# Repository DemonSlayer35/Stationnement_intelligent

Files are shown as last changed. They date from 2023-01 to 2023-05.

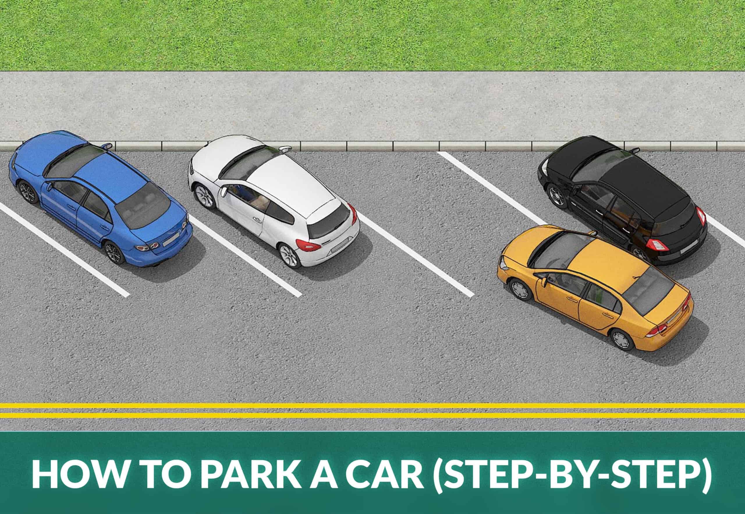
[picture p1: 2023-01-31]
data_parking/1images/HOW-TO-PARK-A-CAR-STEP-BY-STEP-scaled.jpg

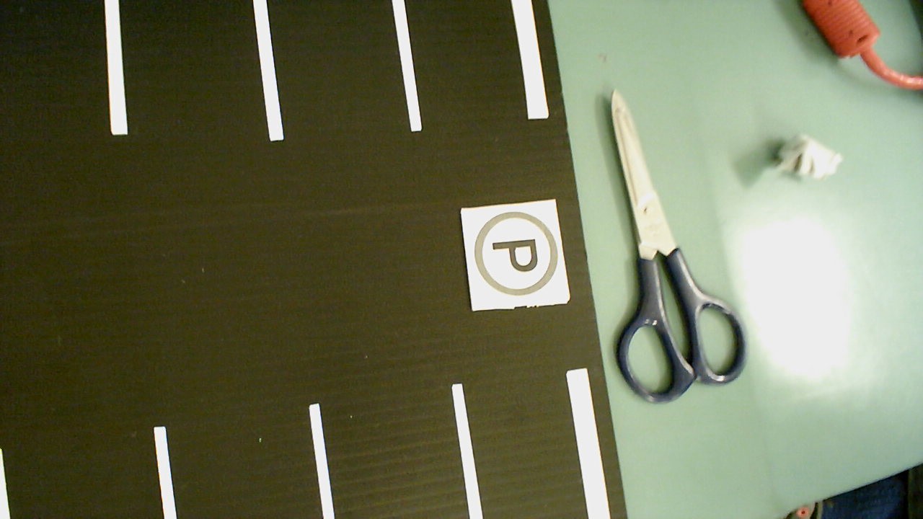
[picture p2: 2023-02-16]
data_parking/images/WIN_20230214_13_57_14_Pro.jpg

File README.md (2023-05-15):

# Stationnement intelligent
Projet de fin de DEC en TSO (Etienne Dubé et Mohammad Barin Wahidi)

## Pour démarrer le projet, il faut d'abord suivre les étapes d'installation des fichiers Installation.md 
(Stationnement_intelligent/Installation.md et Stationnement_intelligent/code_esp/Installation.md)
https://github.com/DemonSlayer35/Stationnement_intelligent/blob/main/Installation.md et
https://github.com/DemonSlayer35/Stationnement_intelligent/blob/main/code_esp/Installation.md

## Ensuite, il faut suivre les étapes d'opération des fichiers Procedure.md
(Stationnement_intelligent/page_web/Procedure.md et Stationnement_intelligent/code_esp/Procedure.md)
https://github.com/DemonSlayer35/Stationnement_intelligent/blob/main/page_web/Procedure.md et https://github.com/DemonSlayer35/Stationnement_intelligent/blob/main/code_esp/Procedure.md

## Installation.md 
* Ce fichier contient les procédures d'installation de la suite Yolov5 et les étapes pour l'entraînement de l'IA ainsi que la détection d'objets.

## KiCad
* Ce dossier contient le projet KiCad (schéma électrique, PCB et fichiers de fabrication) de l'ESP32 pour la barrière de stationnement.

## code 
* Ce dossier contient les scripts en Python pour la détection des images avec la caméra et l'affichage du stationnement sur un écran.
* Le code envoie les résultats de la détection d'emplacements libres par MQTT au broker pour la construction de la page Web du stationnement.

## code_esp
* Ce dossier contient le code (code_esp.ino) à téléverser dans l'ESP, ainsi que les fichiers (dans le dossier /data) à téléverser dans le système de fichiers de l'ESP32. 
* Le code de l'ESP génère un point d'accès qui sert la page Web du stationnement intelligent via un portail captif.

## data_parking 
* Ce dossier contient les images de stationnement pour l'entraînement de l'IA et les étiquettes correspondantes (vide, plein, logo).
* Sont aussi inclus les modèles résultants de l'entraînement qui permettent de détecter les étiquettes voulues.

## page_web
* Ce dossier contient les fichiers de code pour la génération de la page Web affichant les places de stationnement.

## stl
* Ce dossier contient les fichiers 3D de la barrière.

## schema.drawio
* Ce fichier est un schéma bloc du fonctionnement du projet de stationnement intelligent (à ouvrir avec draw.io)

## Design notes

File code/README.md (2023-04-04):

# camera.py 
Contient une version améliorée de Projet.py (ajout de la moyenne des résultats, numérotation des parkings et simplification du code).

# ClassCamera.py
Tentative d'Etienne d'améliorer camera.py pour gérer plusieurs caméras à la fois.

# Projet.py 
Contient un code en Python qui permet de détecter les voitures dans le stationnement en traçant des rectangles autour des emplacements.

# ecran.py
Contient un code en Python pour l'affichage graphique du stationnement.

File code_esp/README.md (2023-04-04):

## Installation.md 
* Ce fichier contient les procédures d'installation du board ESP32 et des librairies pour le code dans l'IDE Arduino.

## Procedure.md
* Procédure pour faire rouler l'ESP en mode point d'accès avec un portail captif affichant le schéma du stationnement

## code_esp.ino
* Code à téléverser dans l'ESP32 pour générer un point d'accès qui sert la page Web du stationnement intelligent via un portail captif.
* L'ESP est mis en mode point d'accès et en mode station.
* Le côté station se connecte au réseau spécifié. Cette connexion servira à la récupération des données MQTT depuis le broker.
Il faut donc que le broker soit connecté au même réseau.
* Le côté point d'accès permet aux usagers de se connecter à l'ESP.
* Via un serveur DNS, les usagers connectés au point d'accès sont redirigés vers le portail captif.
* Lorsqu'un message (la liste de places libres) est reçu par MQTT, le point de terminaison (endpoint) HTTP à l'adresse "/content" est mis à jour avec
le contenu de la nouvelle liste.
* Ainsi, lorsque le code javascript effectue (aux 2 secondes) une requête GET vers "/content", il reçoit une réponse contenant le contenu de la liste sous forme de JSON.

## data
* Dossier contenant les fichiers pour la page Web à téléverser dans le système de fichiers de l'ESP.

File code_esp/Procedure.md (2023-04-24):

# Procédure pour faire rouler l'ESP en mode point d'accès avec un portail captif affichant le schéma du stationnement

1. Récupérer le dossier code_esp.
2. Ouvrir le fichier code_esp.ino dans l'IDE Arduino.
3. Connecter l'ESP à l'ordinateur. Sélectionner le type de carte (ex. : ESP32-WROOM-DA Module) et le port correspondant.
Assurez-vous aussi de rentrer les identifiants Wi-Fi correspondants ainsi que l'adresse du broker MQTT.



4. Téléverser le code à l'intérieur de l'ESP. 
(Si la connexion ne fonctionne pas, il faut appuyer sur le bouton BOOT pendant une seconde environ lorsque la console affiche Connecting...)
5. Aller dans Outils > ESP32 Data Sketch Upload et attendre que les fichiers soient téléchargés dans la mémoire.



6. Un point d'accès nommé Parking devrait apparaître dans la liste des réseaux disponibles. En vous y connectant, le schéma
du stationnement devrait apparaître après quelques secondes.

(Vous pouvez vérifier dans le moniteur série de l'IDE Arduino si tout est fonctionnel.)

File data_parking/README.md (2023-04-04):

## bestv5m.pt
* Le dernier modèle de détection entraîné pour détecter les logos de parking ainsi que les emplacements libres et occupés.

## hyps
* Contient les paramètres d'entraînement supplémentaires (translation, rotation, homothétie, etc.)

## images
* Contient les images utilisées pour l'entraînement de l'intelligence artificielle.

## labels
* Contient les étiquettes (vide, plein, logo) associées aux images de l'entraînement.

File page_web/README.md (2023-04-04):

## Procedure.md
* Procédure pour faire rouler la page Web contenant le schéma du stationnement accessible à tous

## page_web.html
* Ce fichier HTML contient une page web qui affiche un canevas avec une texture d'asphalte. 

* Le canevas s'ajuste selon la taille de l'affichage. 

* Le script JavaScript situé dans le fichier "C:/nginx-1.23.3/js/script.js" est chargé sur la page web.

* C'est le script qui se charge de dessiner les emplacements de stationnement.

## script.js
* Ce fichier JavaScript est utilisé pour dessiner une grille de parkings sur un canevas HTML et
pour récupérer une liste de disponibilité de ces parkings à partir d'un serveur MQTT (Mosquitto).

* Il commence par définir les dimensions de l'écran de dessin et la variable "obj" qui sera utilisée pour stocker les données récupérées depuis le topic MQTT.

* Ensuite, il va récupérer les données du topic MQTT en utilisant l'URL du serveur MQTT (IP de l'hôte:8080).

* Les parkings disponibles sont remplis de vert et les parkings occupés sont remplis de rouge. Les numéros de parking sont également affichés à l'intérieur des rectangles.

* Toutes les 2 secondes, les données affichées sur le canevas HTML sont mises à jour.

## test_web.py
* Ce fichier est un script Python pour tester la publication de la liste en MQTT au lieu de Flask.

* Dans le code, il y a une boucle qui change l'état des stationnements aux secondes.

## app.py (Remplacé par MQTT)
~~* Le fichier app.py est un programme Python qui utilise le framework Flask pour créer une API web. 
L'API permet au fichier camera.py de mettre à jour la liste moyenne de l'état des 18 stationnements.~~

~~* Lorsqu'un utilisateur envoie une requête GET à la route "/moyenne", l'API renvoie la liste moyenne sous forme de JSON.~~

~~* Lorsque camera.py envoie une requête POST à la route "/moyenne" avec une liste de 18 valeurs, 
l'API met à jour la liste moyenne avec les nouvelles valeurs et renvoie la liste mise à jour sous forme de JSON.~~

~~* Le module flask_cors est également utilisé pour permettre l'accès à l'API depuis n'importe quel site web,
en contournant les restrictions de sécurité normalement en place pour les requêtes effectuées à partir de sites tiers.~~

~~* Il faut installer flask avec ```pip install flask``` et flask_cors avec ```pip install -U flask-cors```.~~

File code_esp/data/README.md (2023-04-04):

## captive_portal.html
* Ce fichier HTML contient une page web qui affiche un canevas avec un fond gris. 

* Le canevas s'ajuste selon la taille de l'affichage. 

* Le script JavaScript situé dans le même dossier est chargé sur la page web.

* C'est le script qui se charge de dessiner les emplacements de stationnement.

## script.js
* Ce fichier JavaScript est utilisé pour dessiner une grille de parkings sur un canevas HTML et
pour récupérer une liste de disponibilité de ces parkings à partir d'un serveur MQTT (Mosquitto).

* Il commence par définir les dimensions de l'écran de dessin et la variable "obj" qui sera utilisée pour stocker les données de la liste de places JSON.

* Les parkings disponibles sont remplis de vert et les parkings occupés sont remplis de rouge. Les numéros de parking sont également affichés à l'intérieur des rectangles.

* Toutes les 2 secondes, il va récupérer les données depuis l'endpoint /content pour mettre à jour les données affichées sur le canevas HTML.

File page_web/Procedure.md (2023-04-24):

# Procédure pour faire rouler la page Web contenant le schéma du stationnement accessible à tous

1. Installer paho-mqtt (client MQTT) avec ```pip install paho-mqtt``` dans une console cmd.
Télécharger NGINX à partir du site officiel : https://nginx.org/en/download.html, puis décompresser le dossier.

2. Récupérer les fichiers page_web.html (dans page_web), script.js (dans page_web), camera.py (dans code) et le modèle bestv5m.pt (dans data_parking).

3. Créer un dossier js (pour les fichiers JavaScript) dans le répertoire de NGINX et y déposer script.js :



4. Placer le fichier page_web.html dans le dossier html de NGINX.

5. Ouvrir le fichier nginx.conf (configuration de NGINX) situé dans le dossier conf de NGINX :



6. Dans la section non-commentée commençant par server{listen 80;, ajouter un bloc pour l'emplacement du dossier JavaScript comme suit :



(Mettre le chemin correspondant en conséquence.)

7. Enregistrer le fichier et fermer nginx.conf (Notez qu'il faut repartir nginx.exe à chaque modification.)

8. Modifier le fichier script.js en entrant l'adresse IP de l'hôte pour la connexion MQTT et le bon nom de topic:
```
// Créez un nouveau client MQTT
const client = new Paho.Client("10.240.9.128", 8080, "myclientid_");
const topic = "parking/A";
```

9. Enregistrer le fichier et repartir nginx.exe

10. Assurez-vous que le chemin du modèle utilisé est correct dans le fichier camera.py 
  - ``` model = torch.hub.load('C:/yolov5', 'custom', path='C:/yolov5/Stationnement_intelligent/data_parking/bestv5m.pt', source='local') ```

11. Assurez-vous que la bonne caméra est utilisée dans le fichier camera.py 
  - ```cap = cv2.VideoCapture(0)  # 0 = Webcam intégrée ; 1 = Caméra USB```

12. Démarrer NGINX en double-cliquant sur nginx.exe (C'est normal si rien ne s'affiche.)
  - Si vous voulez être sûr que NGINX fonctionne, aller à l'adresse localhost et vous devriez voir la page index.html suivante :



13. Télécharger Mosquitto à partir du site officiel : https://mosquitto.org/download/.

14. Ouvrir le fichier de configuration de Mosquitto (C:\Program Files\mosquitto\mosquitto.conf) 
et ajouter les lignes suivantes à la fin du fichier:
```
listener 1883
listener 8080 
protocol websockets
allow_anonymous true
socket_domain ipv4
```


15. Démarrer le serveur Mosquitto avec la commande ```mosquitto -c mosquitto.conf``` dans une console cmd.
(Si la console affiche que le serveur est déjà occupé, vous pouvez tuer le service Mosquitto à partir des Services Windows ou avec
la commande ```taskkill /im mosquitto.exe /f``` dans une console cmd exécutée en tant qu'administrateur.

16. Exécuter le fichier 📷camera.py depuis une console cmd avec ```py camera.py```.
  - Cela va démarrer la détection des emplacements de stationnement. Après chaque cycle de 20 frames, la liste est mise à jour sur le serveur Mosquitto
  à [l'adresse IP de l'hôte]:1883
  (La page va se mettre à jour avec les données MQTT envoyées au port 8080).

17. Accéder au 🕸️site Web à [l'adresse IP de l'hôte]/page_web.html
(Les autres usagers peuvent aussi accéder à la page.)



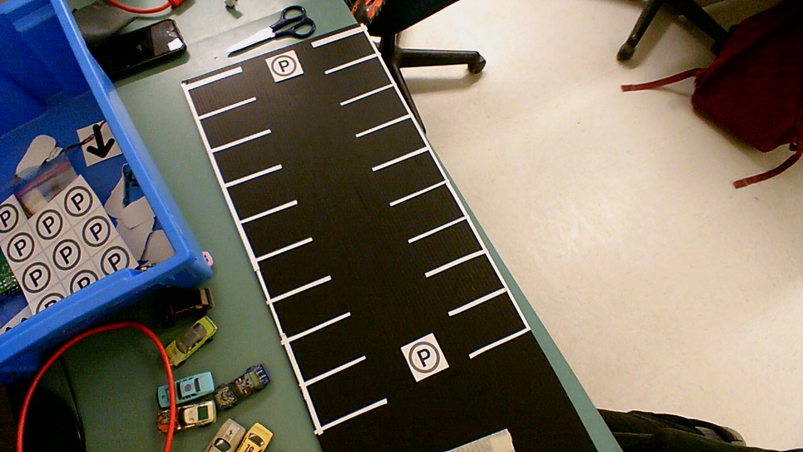
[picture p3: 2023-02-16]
data_parking/images/WIN_20230214_13_57_02_Pro.jpg

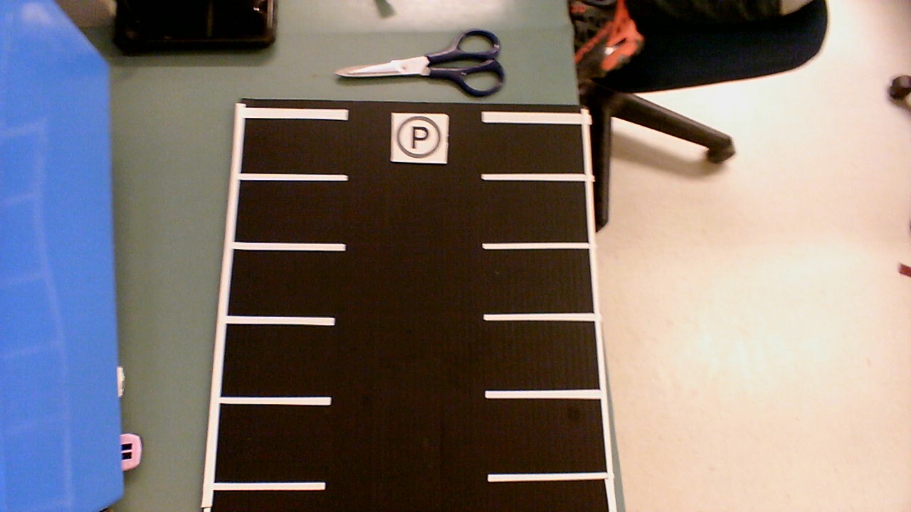
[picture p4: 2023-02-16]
data_parking/images/WIN_20230214_13_57_19_Pro.jpg

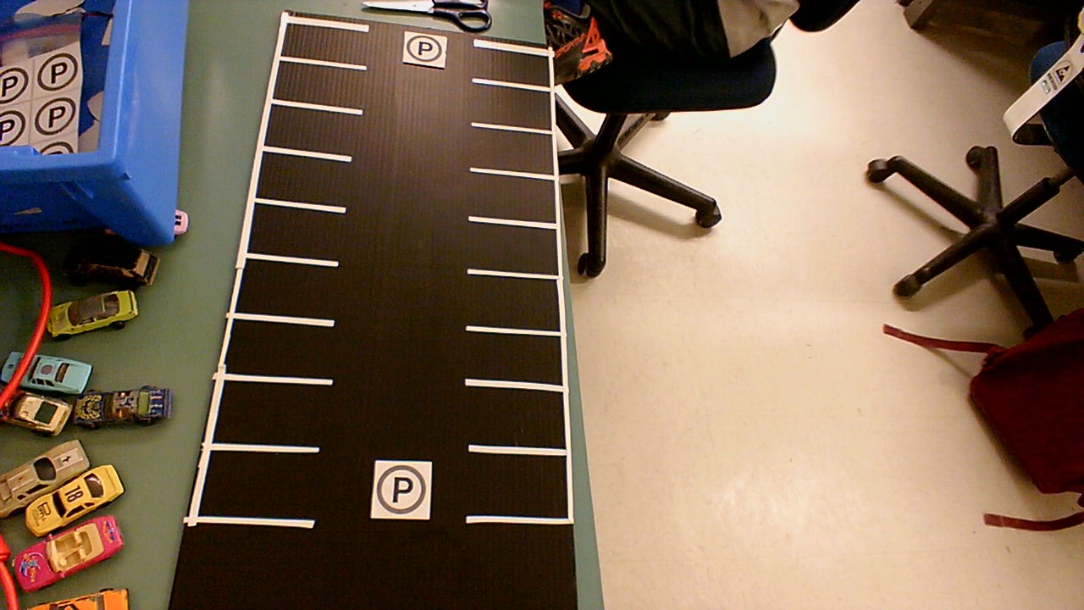
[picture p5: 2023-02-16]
data_parking/images/WIN_20230214_13_56_37_Pro.jpg

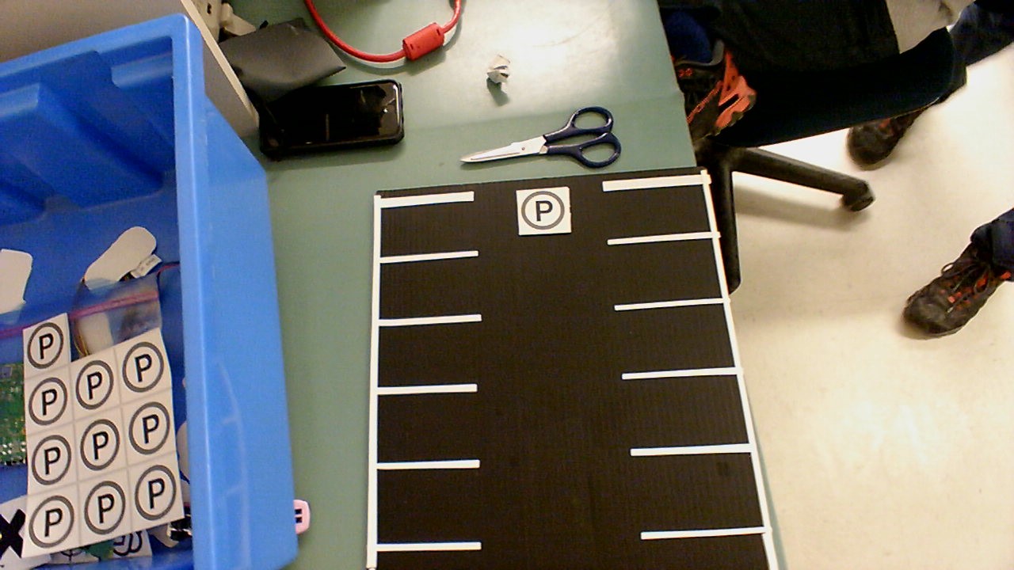
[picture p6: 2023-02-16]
data_parking/images/WIN_20230214_13_57_23_Pro.jpg

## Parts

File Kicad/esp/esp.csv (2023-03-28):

# | Reference | Qty | Value | Footprint | DNP
1 | C1, C2, C3, C4, C5, C6, C7 | 7 | 0.1µ | Capacitor_SMD:C_0805_2012Metric_Pad1.18x1.45mm_HandSolder
2 | D1 | 1 | LED_TX_Bleu | LED_SMD:LED_0805_2012Metric_Pad1.15x1.40mm_HandSolder
3 | D2 | 1 | LED_RX_Rouge | LED_SMD:LED_0805_2012Metric_Pad1.15x1.40mm_HandSolder
4 | D3 | 1 | D_Schottky | Diode_SMD:D_0805_2012Metric_Pad1.15x1.40mm_HandSolder
5 | J1, J2 | 2 | ~ | TerminalBlock:TerminalBlock_bornier-2_P5.08mm
6 | J3 | 1 | LED_R | Connector_PinHeader_2.54mm:PinHeader_1x02_P2.54mm_Vertical
7 | J4 | 1 | SW_Open | Connector_PinHeader_2.54mm:PinHeader_1x02_P2.54mm_Vertical
8 | J5 | 1 | Sensor_car_in | Connector_PinHeader_2.54mm:PinHeader_1x03_P2.54mm_Vertical
9 | J6 | 1 | Sensor_gate_open | Connector_PinHeader_2.54mm:PinHeader_1x03_P2.54mm_Vertical
10 | J7 | 1 | LED_V | Connector_PinHeader_2.54mm:PinHeader_1x02_P2.54mm_Vertical
11 | J8 | 1 | SW_Close | Connector_PinHeader_2.54mm:PinHeader_1x02_P2.54mm_Vertical
12 | J9 | 1 | Sensor_car_out | Connector_PinHeader_2.54mm:PinHeader_1x03_P2.54mm_Vertical
13 | J10 | 1 | Sensor_gate_close | Connector_PinHeader_2.54mm:PinHeader_1x03_P2.54mm_Vertical
14 | J11, J12 | 2 | Conn_01x19_Pin | Connector_PinHeader_2.54mm:PinHeader_1x19_P2.54mm_Vertical
15 | K1, K2 | 2 | FINDER-30.22 | Relay_THT:Relay_DPDT_Finder_30.22
16 | P1 | 1 | USB_C_Plug_USB2.0 | Connector_USB:USB_C_Receptacle_GCT_USB4105-xx-A_16P_TopMnt_Horizontal
17 | Q1, Q2 | 2 | NPN | Package_TO_SOT_SMD:SOT-23
18 | R1, R2, R9, R10, R16, R21 | 6 | 10K | Resistor_SMD:R_0805_2012Metric_Pad1.20x1.40mm_HandSolder
19 | R3, R4, R11, R12, R13, R15, R17 | 7 | R | Resistor_SMD:R_0805_2012Metric_Pad1.20x1.40mm_HandSolder
20 | R5, R6 | 2 | 150 | Resistor_SMD:R_0805_2012Metric_Pad1.20x1.40mm_HandSolder
21 | R7, R8 | 2 | 330 | Resistor_SMD:R_0805_2012Metric_Pad1.20x1.40mm_HandSolder
22 | R14, R20 | 2 | 300 | Resistor_SMD:R_0805_2012Metric_Pad1.20x1.40mm_HandSolder
23 | R18, R19 | 2 | 470 | Resistor_SMD:R_0805_2012Metric_Pad1.20x1.40mm_HandSolder
24 | SW1, SW2 | 2 | SW_Push | Button_Switch_SMD:SW_SPST_CK_RS282G05A3
25 | U1 | 1 | AMS1117-3.3 | Package_TO_SOT_SMD:SOT-223-3_TabPin2
26 | U2 | 1 | FT232RL | Package_SO:SSOP-28_5.3x10.2mm_P0.65mm
27 | U3 | 1 | ULN2003 | Package_SO:SO-16_3.9x9.9mm_P1.27mm
28 | U4 | 1 | ESP32-WROOM-E | Espressif:ESP32-WROOM-32E

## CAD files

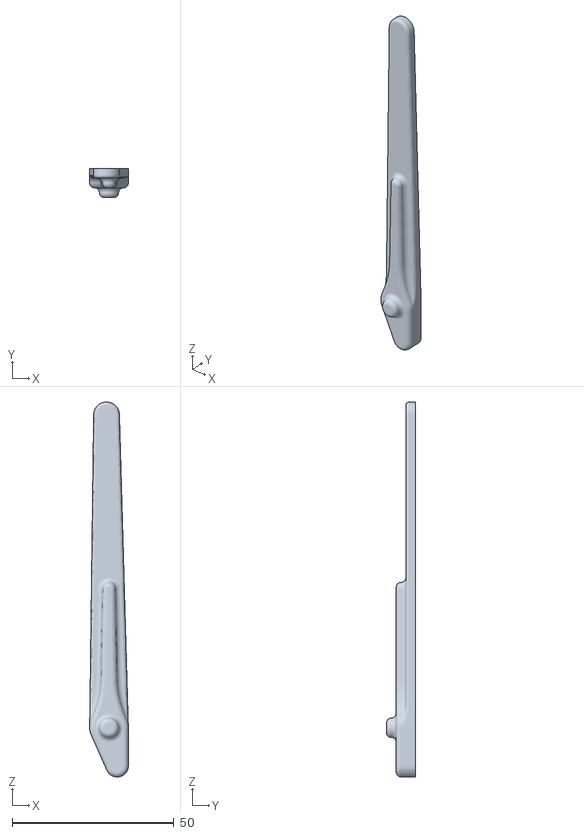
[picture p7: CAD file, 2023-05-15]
stl/lever_gate.stl
12.0 x 9.00 x 116.0

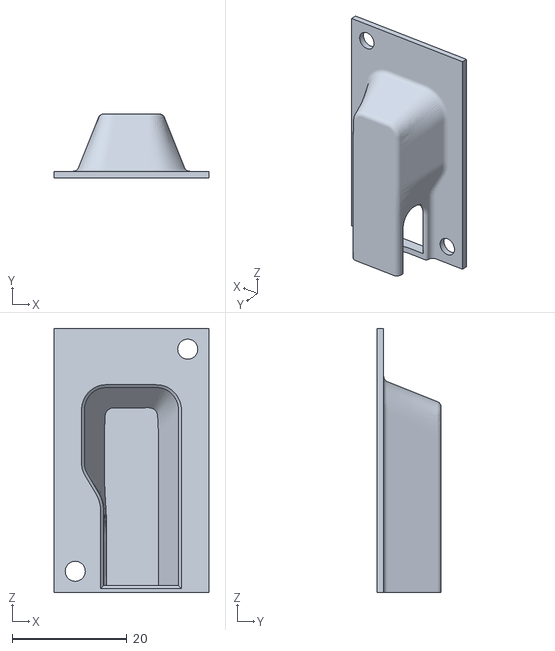
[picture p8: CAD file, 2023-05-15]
stl/cover_gate.stl
27.0 x 11.2 x 46.0

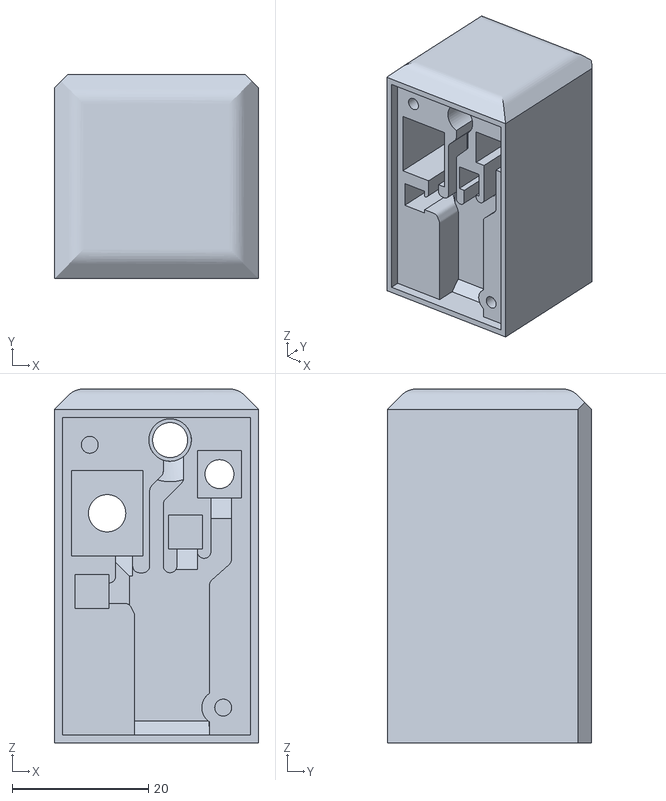
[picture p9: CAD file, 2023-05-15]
stl/stand_gate.stl
30.0 x 30.0 x 52.0

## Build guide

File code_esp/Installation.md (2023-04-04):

## Installer le board ESP32 dans l’IDE Arduino. (https://randomnerdtutorials.com/installing-the-esp32-board-in-arduino-ide-windows-instructions/)
1.	Dans l'IDE Arduino (pas 2.0), aller dans Fichier> Préférences



2.	Entrer l'adresse suivante dans le champ “URL de gestionnaire de cartes supplémentaires” :
https://raw.githubusercontent.com/espressif/arduino-esp32/gh-pages/package_esp32_index.json
Puis, cliquer sur le bouton “OK”:

 
 
3.	Ouvrir le Gestionnaire de carte. Aller dans Outils > Type de carte > Gestionnaire de carte

 

4.	Chercher ESP32 et appuyer sur le bouton Installer de “esp32 by Espressif Systems“:

 

## Installer ESP32 Filesystem Uploader dans l’IDE Arduino (https://randomnerdtutorials.com/install-esp32-filesystem-uploader-arduino-ide/)

1) Aller à l'adresse suivante https://github.com/me-no-dev/arduino-esp32fs-plugin/releases/ et télécharger le dossier compressé ESP32FS-1.0.zip

 
 
2) Trouver le dossier des croquis. Dans l'IDE Arduino, aller dans Fichier > Préférences et afficher le dossier des croquis.
Par exemple, le chemin peut ressembler à cela: C:\Users\user\Documents\Arduino.

 
 
3) Aller dans le dossier des croquis et créer un dossier tools.

 
 
4) Décompresser le dossier .zip. Ouvrez-le et copiez le dossier ESP32FS dans le dossier tools précédemment créé.
La structure de fichier devrait ressembler à: <Dossier-des-croquis>/tools/ESP32FS/tool/esp32fs.jar
  
 
 
5) Finalement, redémarrer (rouvrir) l'IDE Arduino. Pour vérifier si le plugin a été installé correctement, ouvrir l'IDE Arduino.
Sélectionner votre board ESP32, aller dans Outils et vérifier que vous avez l'option “ESP32 Sketch Data Upload“.
  
 

Pour le MQTT, il faut installer la libraire PubSubClient via Outils > Gérer les bibliothèques

 
  
## Installer la librairie ESPAsyncWebServer
 
1) Cliquer sur ce lien https://github.com/me-no-dev/ESPAsyncWebServer/archive/master.zip pour télécharger la librairie.
 
2) Décompresser le dossier .zip. Vous devriez obtenir un dossier ESPAsyncWebServer-master.
 
3) Renommer le dossier ESPAsyncWebServer-master en ESPAsyncWebServer.
 
4) Déplacer le dossier ESPAsyncWebServer vers votre dossier de libraires pour l'IDE Arduino.
Par exemple, le chemin peut ressembler à cela: C:\Users\user\Documents\Arduino\libraries.
 

 
## Installer la librairie Async TCP
 
1) Cliquer sur ce lien https://github.com/me-no-dev/AsyncTCP/archive/master.zip pour télécharger la librairie.
 
2) Décompresser le dossier .zip. Vous devriez obtenir un dossier AsyncTCP-master.
 
3) Renommer le dossier AsyncTCP-master en AsyncTCP.
 
4) Déplacer le dossier AsyncTCP vers votre dossier de libraires pour l'IDE Arduino.
Par exemple, le chemin peut ressembler à cela: C:\Users\user\Documents\Arduino\libraries.
 


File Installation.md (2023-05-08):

# Étapes d'installation de YOLOv5 sur Windows avec une carte graphique NVIDIA
1. Télécharger le fichier zip du répertoire de YOLOv5 à l'adresse https://github.com/ultralytics/yolov5
   ou cloner le répertoire GitHub (si vous avez Git installé sur votre PC) de YOLOv5 depuis une invite de commandes avec la commande :
   
    git clone https://github.com/ultralytics/yolov5

2. Installer une version de Python entre 3.7 et 4.0, comme Python 3.9.7 depuis le site de Python :
    https://www.python.org/downloads/release/python-397/
    
    

3. Si vous possédez une carte graphique NVIDIA, installer le logiciel Cuda depuis le site de NVIDIA :
    https://developer.nvidia.com/cuda-downloads
    
    

4. Aller sur le site de PyTorch à l'adresse https://pytorch.org/get-started/locally/

5. Sélectionner les options correspondantes (Stable, Windows, Pip, Python, Cuda 11.7) et copier la commande proposée par PyTorch.



6. Dans l'explorateur de fichiers, trouver le dossier Scripts de Python. Dans mon cas, le fichier se trouve à l'adresse : 
    C:\Users\user\AppData\Local\Programs\Python\Python39\Scripts
    
7. Taper cmd dans la barre d'adresse de l'explorateur de fichiers pour ouvrir l'invite de commandes.
 


8. Coller la commande de PyTorch dans la console.

9. Ouvrir le dossier YOLOv5 et taper cmd dans la barre d'adresse de l'explorateur de fichiers pour ouvrir l'invite de commandes.

10. Installer les requis de YOLOv5 en tapant la commande :
      ```pip install -r requirements.txt```
      
11. Vérifier la fonctionnalité de l'installation en tapant la commande : 
      ```python detect.py --source 0```
      (Cette commande doit être utilisée à partir du dossier de YOLOv5, car c'est là que le fichier detect.py se trouve.)
      (Cette commande va utiliser la webcam pour détecter les objets avec un script déjà fait.)
      
# Création d'un dataset pour l'entraînement de l'intelligence artificielle
1. Installer un logiciel qui permet d'étiqueter des images comme LabelImg avec la commande (depuis une invite de commandes) : 
      ```pip install labelImg```
      (Il faut identifier manuellement avec des étiquettes les objets qu'on veut détecter dans les images choisies. C'est
      là l'utilité d'un logiciel comme LabelImg qui permet de rapidement tracer des rectangles sur des images et qui fournit
      un format de sortie compatible avec YOLOv5.)
      
2. Créer un dossier pour le dataset. Dans ce dossier, créer un dossier pour les images et un autre pour les étiquettes.

![image](https://user-images.githubusercontent.com/89463240/217083315-a7eb631a-94e3-46ff-b341-b584e103f759.png)

3. Ouvrir LabelImg depuis un terminal avec la commande labelimg

4. Dans la barre latérale à gauche, sélectionner le format Yolo. Vous pouvez ouvrir votre dossier d'images avec Open Dir
   et changer le dossier d'enregistrement des étiquettes avec Change Save Dir.

![image](https://user-images.githubusercontent.com/89463240/217080357-236bfc18-899d-40ae-920c-2924421705e5.png)

5. Vous pouvez tracer des rectangles autour des objets dans l'image et assigner une étiquette à chaque rectangle.

![image](https://user-images.githubusercontent.com/89463240/217081390-8417ba8f-8f6f-4fc5-9623-ec851b5d6666.png)

6. Enregistrer vos changements avec le bouton Save.

# Entraînement de l'intelligence artificielle
1. Copier le dossier hyps des hyperparamètres (yolov5\data\hyps) et le coller dans le dossier du dataset.

2. Créer un fichier yml pour le dataset dans le répertoire yolov5

3. Dans le fichier yml, spécifier le chemin des images, le nombre de classes et le nom des classes.
(Les classes correspondent aux étiquettes.)

![image](https://user-images.githubusercontent.com/89463240/217090070-ecd2543e-f5da-4cbd-bb6c-4416c26e8cac.png)

(Dans cette image, le dossier du dataset est nommé data_vache et il est situé dans le répertoire yolov5 sur le PC.)

4. Vous pouvez modifier les hyperparamètres à partir du fichier hyp.scratch.yaml (Ce sont des paramètres qui permettent
   d'améliorer l'entraînement comme la rotation ou la translation des images.)

5. Ouvrir cmd à partir du dossier yolov5 et entraîner l'intelligence en tapant la commande :

```python train.py --img 320 --batch 16 --epochs 50 --data dataset_vache.yml --weights yolov5s.pt --workers 4 --hyp data_vache\hyps\hyp.scratch.yaml```

* img définit la résolution des images 
* batch définit le nombre d'images par section d'entraînement
* epochs définit le nombre de fois que toutes les images passent à travers le réseau de neurones
* data pointe vers le fichier yml à utiliser
* weights définit le modèle à utiliser pour l'entraînement
* workers définit le nombre de coeurs CPU à utiliser
* hyp pointe vers le fichier des hyperparamètres

6. À la fin de l'entraînement, la console affichera le dossier où les résultats ont été enregistrés. En général, c'est
   quelque chose du genre yolov5/runs/train/exp
   
# Test de détection (validation) avec un modèle personnalisé
1. Ouvrir cmd à partir du dossier yolov5 et démarrer la détection en tapant la commande :

```python detect.py --weights runs/train/exp/weights/best.pt --img 320 --conf 0.25 --source data_vache/images/```

(Dans weigths, spécifier le chemin du modèle entraîné.
Dans conf, spécifier le seuil de confiance entre 0 et 1 de l'intelligence pour la détection)

2. Dans la console sera affichée le dossier des résultats. En général, c'est quelque chose du genre
   yolov5/runs/detect/exp

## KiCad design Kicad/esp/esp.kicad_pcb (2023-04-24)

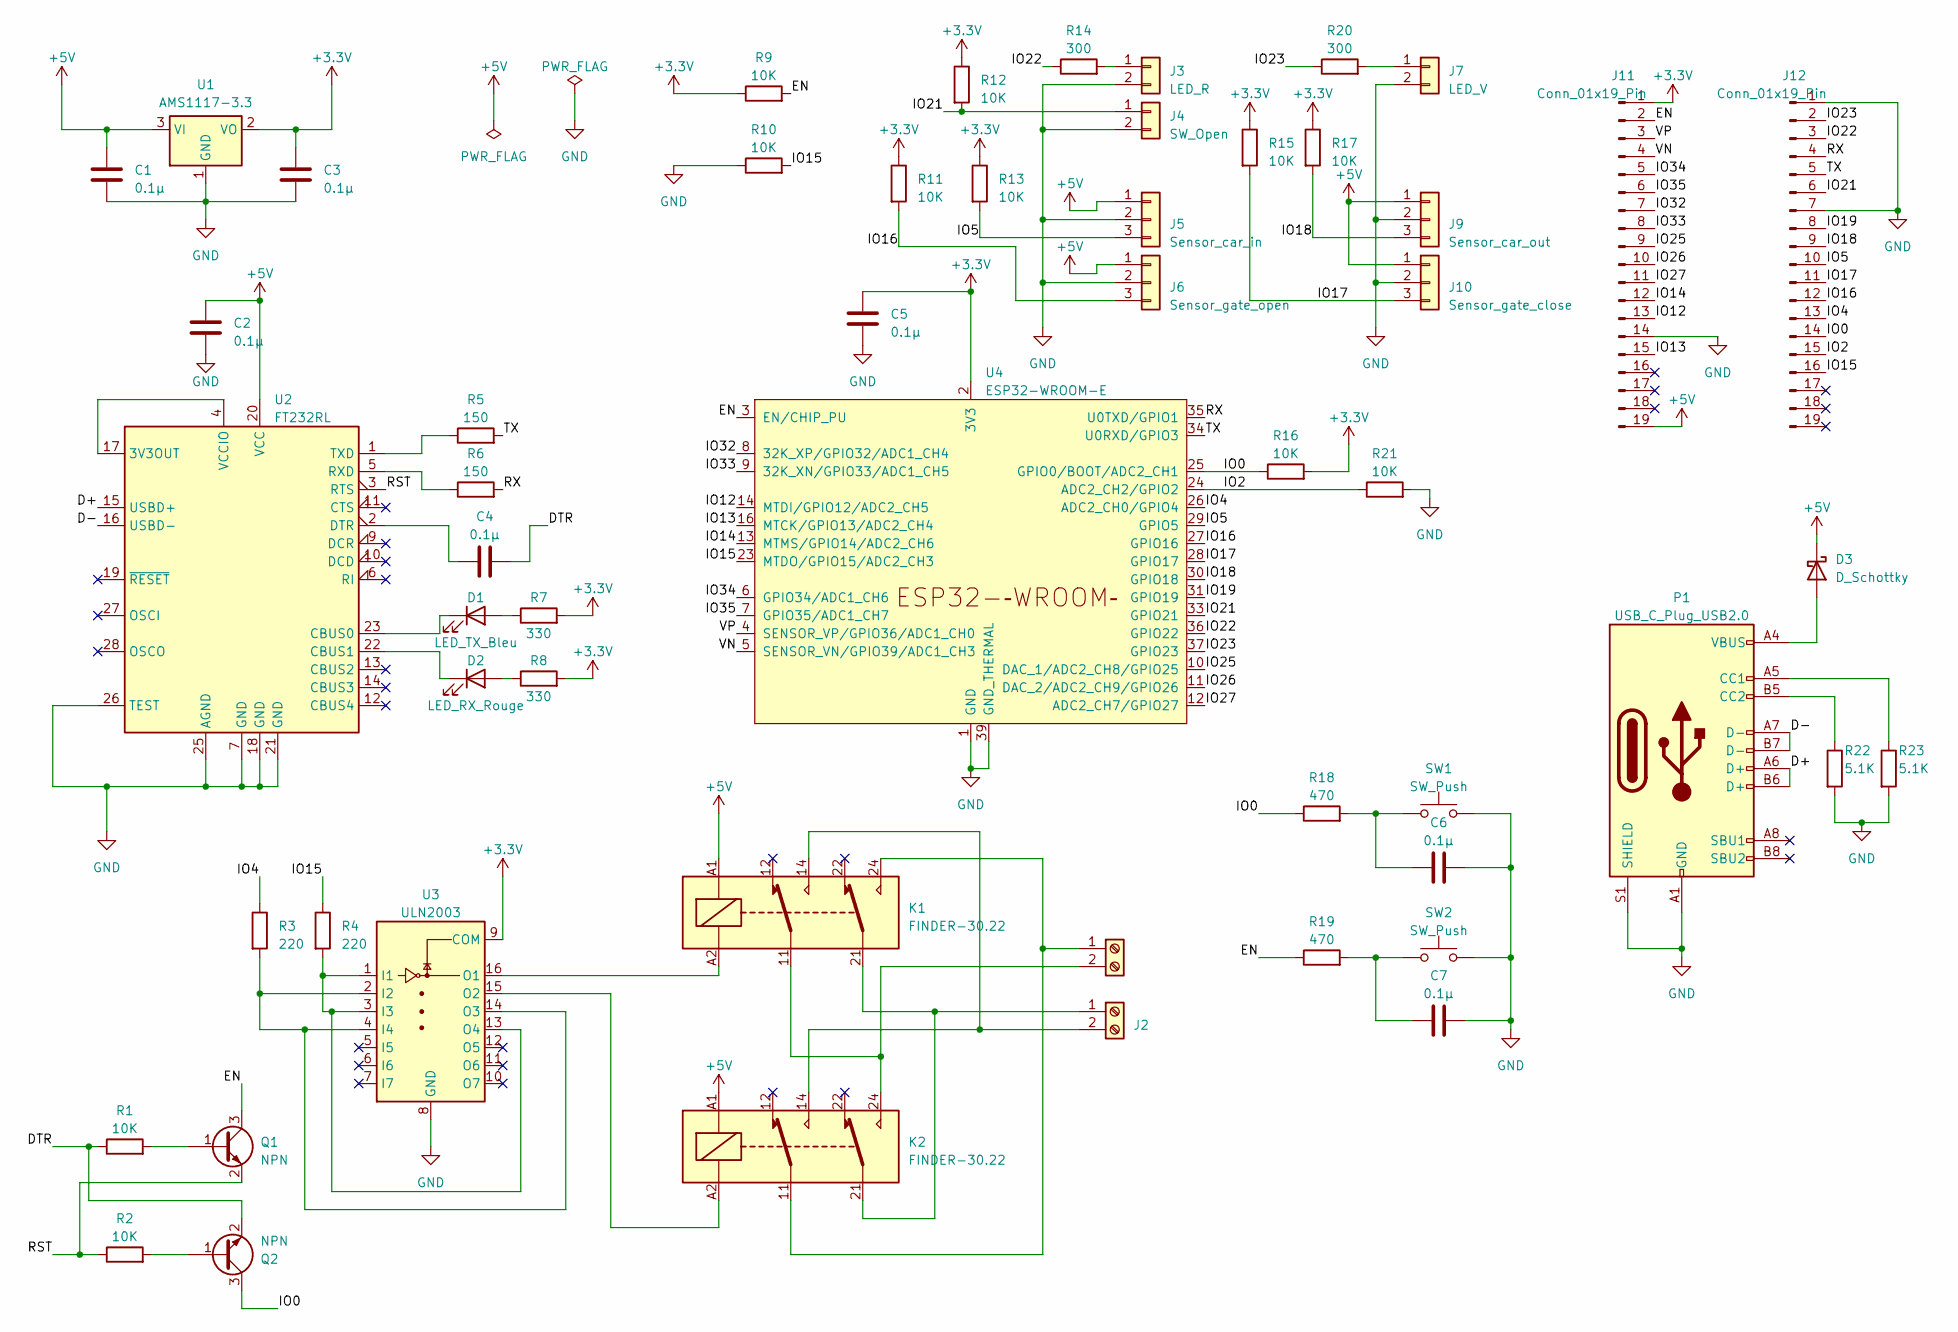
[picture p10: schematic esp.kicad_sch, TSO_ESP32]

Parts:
C1, C2, C3, C4, C5, C6, C7: 0.1µ; C_0805_2012Metric_Pad1.18x1.45mm_HandSolder
D1: LED_TX_Bleu; LED_0805_2012Metric_Pad1.15x1.40mm_HandSolder
D2: LED_RX_Rouge; LED_0805_2012Metric_Pad1.15x1.40mm_HandSolder
D3: D_Schottky; D_0805_2012Metric_Pad1.15x1.40mm_HandSolder
J1, J2: TerminalBlock_bornier-2_P5.08mm
J3: LED_R; PinHeader_1x02_P2.54mm_Vertical
J4: SW_Open; PinHeader_1x02_P2.54mm_Vertical
J5: Sensor_car_in; PinHeader_1x03_P2.54mm_Vertical
J6: Sensor_gate_open; PinHeader_1x03_P2.54mm_Vertical
J7: LED_V; PinHeader_1x02_P2.54mm_Vertical
J9: Sensor_car_out; PinHeader_1x03_P2.54mm_Vertical
J10: Sensor_gate_close; PinHeader_1x03_P2.54mm_Vertical
J11, J12: Conn_01x19_Pin; PinHeader_1x19_P2.54mm_Vertical
K1, K2: FINDER-30.22; Relay_DPDT_Finder_30.22
P1: USB_C_Plug_USB2.0; USB_C_Receptacle_GCT_USB4105-xx-A_16P_TopMnt_Horizontal
Q1, Q2: NPN; SOT-23
R1, R2, R9, R10, R11, R12, R13, R15, R16, R17, R21: 10K; R_0805_2012Metric_Pad1.20x1.40mm_HandSolder
R3, R4: 220; R_0805_2012Metric_Pad1.20x1.40mm_HandSolder
R5, R6: 150; R_0805_2012Metric_Pad1.20x1.40mm_HandSolder
R7, R8: 330; R_0805_2012Metric_Pad1.20x1.40mm_HandSolder
R14, R20: 300; R_0805_2012Metric_Pad1.20x1.40mm_HandSolder
R18, R19: 470; R_0805_2012Metric_Pad1.20x1.40mm_HandSolder
R22, R23: 5.1K; R_0805_2012Metric_Pad1.20x1.40mm_HandSolder
SW1, SW2: SW_Push; SW_SPST_CK_RS282G05A3
U1: AMS1117-3.3; SOT-223-3_TabPin2
U2: FT232RL; SSOP-28_5.3x10.2mm_P0.65mm
U3: ULN2003; SO-16_3.9x9.9mm_P1.27mm
U4: ESP32-WROOM-E; ESP32-WROOM-32E

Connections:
+3.3V: C3.1, C5.1, J11.1, R7.2, R8.2, R9.1, R11.1, R12.1, R13.1, R15.1, R16.2, R17.1, U1.2 (VO), U3.9 (COM), U4.2 (3V3)
+5V: C1.1, C2.1, D3.1 (K), J5.1, J6.1, J9.1, J10.1, J11.19, K1.A1, K2.A1, U1.3 (VI), U2.20 (VCC)
/D+: P1.A6 (D+), P1.B6 (D+), U2.15 (USBD+)
/D-: P1.A7 (D-), P1.B7 (D-), U2.16 (USBD-)
/DTR: C4.2, Q2.2 (E), R1.1
/EN: J11.2, Q1.3 (C), R9.2, R19.1, U4.3 (EN/CHIP_PU)
/IO0: J12.14, Q2.3 (C), R16.1, R18.1, U4.25 (GPIO0/BOOT/ADC2_CH1)
/IO2: J12.15, R21.1, U4.24 (ADC2_CH2/GPIO2)
/IO4: J12.13, R3.1, U4.26 (ADC2_CH0/GPIO4)
/IO5: J5.3, J12.10, R13.2, U4.29 (GPIO5)
/IO12: J11.13, U4.14 (MTDI/GPIO12/ADC2_CH5)
/IO13: J11.15, U4.16 (MTCK/GPIO13/ADC2_CH4)
/IO14: J11.12, U4.13 (MTMS/GPIO14/ADC2_CH6)
/IO15: J12.16, R4.1, R10.2, U4.23 (MTDO/GPIO15/ADC2_CH3)
/IO16: J6.3, J12.12, R11.2, U4.27 (GPIO16)
/IO17: J10.3, J12.11, R15.2, U4.28 (GPIO17)
/IO18: J9.3, J12.9, R17.2, U4.30 (GPIO18)
/IO19: J12.8, U4.31 (GPIO19)
/IO21: J4.1, J12.6, R12.2, U4.33 (GPIO21)
/IO22: J12.3, R14.1, U4.36 (GPIO22)
/IO23: J12.2, R20.1, U4.37 (GPIO23)
/IO25: J11.9, U4.10 (DAC_1/ADC2_CH8/GPIO25)
/IO26: J11.10, U4.11 (DAC_2/ADC2_CH9/GPIO26)
/IO27: J11.11, U4.12 (ADC2_CH7/GPIO27)
/IO32: J11.7, U4.8 (32K_XP/GPIO32/ADC1_CH4)
/IO33: J11.8, U4.9 (32K_XN/GPIO33/ADC1_CH5)
/IO34: J11.5, U4.6 (GPIO34/ADC1_CH6)
/IO35: J11.6, U4.7 (GPIO35/ADC1_CH7)
/RST: Q1.2 (E), R2.1, U2.3 (RTS)
/RX: J12.4, R6.2, U4.35 (U0TXD/GPIO1)
/TX: J12.5, R5.2, U4.34 (U0RXD/GPIO3)
/VN: J11.4, U4.5 (SENSOR_VN/GPIO39/ADC1_CH3)
/VP: J11.3, U4.4 (SENSOR_VP/GPIO36/ADC1_CH0)
GND: C1.2, C2.2, C3.2, C5.2, C6.2, C7.2, J3.2, J4.2, J5.2, J6.2, J7.2, J9.2, J10.2, J11.14, J12.1, J12.7, P1.A1 (GND), P1.A12 (GND), P1.B1 (GND), P1.B12 (GND), P1.S1 (SHIELD), R10.1, R21.2, R22.2, R23.2, SW1.2, SW2.2, U1.1 (GND), U2.7 (GND), U2.18 (GND), U2.21 (GND), U2.25 (AGND), U2.26 (TEST), U3.8 (GND), U4.1 (GND), U4.15 (GND), U4.38 (GND), U4.39 (GND_THERMAL)
unnamed: C6.1, R18.2, SW1.1
unnamed: C7.1, R19.2, SW2.1
unnamed: D1.2 (A), R7.1
unnamed: D1.1 (K), U2.23 (CBUS0)
unnamed: D2.2 (A), R8.1
unnamed: D2.1 (K), U2.22 (CBUS1)
unnamed: D3.2 (A), P1.A4 (VBUS), P1.A9 (VBUS), P1.B4 (VBUS), P1.B9 (VBUS)
unnamed: J1.1, K1.24, K2.11
unnamed: J1.2, K1.11, K2.24
unnamed: J2.1, K1.21, K2.21
unnamed: J2.2, K1.14, K2.14
unnamed: J3.1, R14.2
unnamed: J7.1, R20.2
unnamed: P1.A5 (CC1), R23.1
unnamed: P1.B5 (CC2), R22.1
unnamed: Q1.1 (B), R1.2
unnamed: Q2.1 (B), R2.2
unnamed: U2.4 (VCCIO), U2.17 (3V3OUT)
unnamed: C4.1, U2.2 (DTR)
unnamed: R6.1, U2.5 (RXD)
unnamed: R5.1, U2.1 (TXD)
unnamed: R4.2, U3.1 (I1), U3.3 (I3), U3.13 (O4)
unnamed: R3.2, U3.2 (I2), U3.4 (I4), U3.14 (O3)
unnamed: K1.A2, U3.16 (O1)
unnamed: K2.A2, U3.15 (O2)

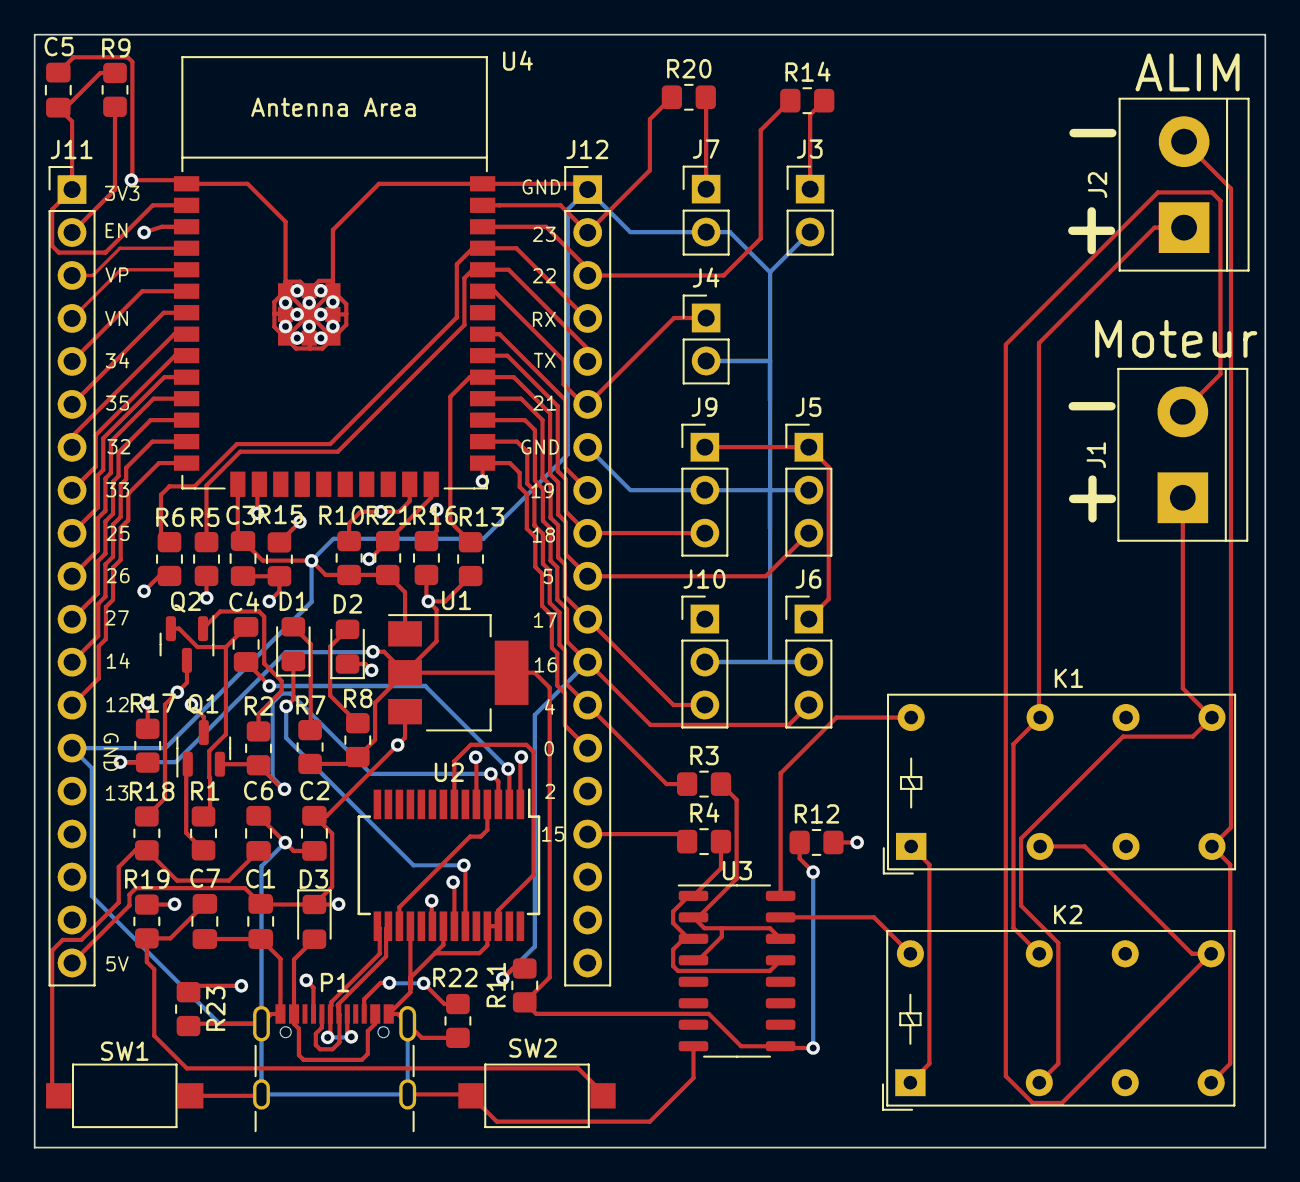
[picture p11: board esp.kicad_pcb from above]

Board: 4 copper layers, 72.7 x 65.8 mm, 55 parts (0 on the bottom side), 59 nets.

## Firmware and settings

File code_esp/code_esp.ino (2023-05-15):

/*
  Projet de gestion de parking avec ESP32 et MQTT
  Auteur : Etienne Dubé, Mohammad Barin Wahidi
  Date : 24 avril 2023

  Description :
  Ce code permet de gérer un parking en utilisant un ESP32 pour contrôler l'accès,
  afficher les informations sur un serveur web et communiquer avec un broker MQTT.
  Le système contrôle l'ouverture et la fermeture de la barrière en fonction du nombre
  de places disponibles. Les informations sur les places sont récupérées via MQTT
  et affichées sur une page web hébergée sur l'ESP32.
*/

#include <DNSServer.h>
#include <WiFi.h>
#include <AsyncTCP.h>
#include "ESPAsyncWebServer.h"
#include "FS.h"
#include "SPIFFS.h"
#include <PubSubClient.h>

const char* ssid     = "tge_sansfil_283";       /*Remplacer par le SSID de votre réseau*/
const char* password = "sherbrooke"; /*Remplacer par le mot de passe de votre réseau*/

// MQTT Broker
const char *mqtt_broker = "10.240.9.128"; /*Remplacer par l'adresse IP du broker MQTT*/
const char *topic = "parking/A";           /*Remplacer par le topic MQTT*/
const int mqtt_port = 1883;

/********Barriere*******/
#define RED_LIGHT 23
#define GREEN_LIGHT 22
#define GATE_OPEN 18
#define GATE_CLOSE 17
#define AVANT 5
#define APRES 16
#define OUVERTURE 15
#define FERMETURE 4

int c_open = 0;
int c_close = 0;
int c_avant = 0;
int c_apres = 0;
int count = 0;

WiFiClient espClient;
PubSubClient client(espClient);

DNSServer dnsServer;
AsyncWebServer server(80);

String liste = ""; // string pour stocker la liste JSON des données du parking

// Fonction pour lister les fichiers sur le système de fichiers SPIFFS.
void listDir(fs::FS &fs, const char * dirname, uint8_t levels){
   Serial.printf("Listing directory: %s\r\n", dirname);

   File root = fs.open(dirname);
   if(!root){
      Serial.println("− failed to open directory");
      return;
   }
   if(!root.isDirectory()){
      Serial.println(" − not a directory");
      return;
   }

   File file = root.openNextFile();
   while(file){
      if(file.isDirectory()){
         Serial.print("  DIR : ");
         Serial.println(file.name());
         if(levels){
            listDir(fs, file.name(), levels -1);
         }
      } else {
         Serial.print("  FILE: ");
         Serial.print(file.name());
         Serial.print("\tSIZE: ");
         Serial.println(file.size());
      }
      file = root.openNextFile();
   }
}

// Classe pour gérer les requêtes de type captive portal
class CaptiveRequestHandler : public AsyncWebHandler {
public:
  CaptiveRequestHandler() {}
  virtual ~CaptiveRequestHandler() {}

  bool canHandle(AsyncWebServerRequest *request){
    return true;
  }

  void handleRequest(AsyncWebServerRequest *request) {
    request->send(SPIFFS, "/captive_page.html","text/html", false);
  }
};

// Fonction pour mettre à jour la page Web avec les données du parking
void update(){
  server.on("/content", HTTP_GET, [](AsyncWebServerRequest *request){
    request->send(200, "text/json", liste);
  });
}

// Fonction pour configurer le serveur Web
void setupServer(){
  // Route qui répond à une requête HTTP GET sur la page d'accueil
  server.on("/", HTTP_GET, [](AsyncWebServerRequest *request){
      request->send(SPIFFS, "/captive_page.html","text/html", false); 
      Serial.println("Client Connected");
  });
   
  // Route qui répond à une requête HTTP GET sur le fichier JavaScript
  server.on("/script.js", HTTP_GET, [](AsyncWebServerRequest *request){
    request->send(SPIFFS, "/script.js", "text/js");
  });
   
  // Route qui répond à une requête HTTP GET sur le contenu du parking (format JSON)
  server.on("/content", HTTP_GET, [](AsyncWebServerRequest *request){
    request->send(200, "text/json", liste);
  });
}

void setup(){
  Serial.begin(115200);
   
  // Initialisation de SPIFFS (système de fichiers)
  if(!SPIFFS.begin(true)){
    Serial.println("An Error has occurred while mounting SPIFFS");
    return;
  }
  
  //Lister le contenu du système de fichiers SPIFFS
  listDir(SPIFFS, "/", 0);

  // Configuration du mode d'opération de l'ESP32 (WIFI_AP_STA)
  Serial.println("Setting up AP Mode");
  WiFi.mode(WIFI_AP_STA); 
  WiFi.softAP("Parking"); // Configuration du nom de l'AP (point d'accès)
  
  Serial.print("AP IP address: ");
  Serial.println(WiFi.softAPIP()); // Affiche l'adresse IP de l'AP
  Serial.println("Setting up Async WebServer");
  setupServer(); // Configuration du serveur web
  
  Serial.println("Starting DNS Server");
  dnsServer.start(53, "*", WiFi.softAPIP()); // Démarrer le serveur DNS
  server.addHandler(new CaptiveRequestHandler()).setFilter(ON_AP_FILTER); //only when requested from AP

  server.begin(); // Démarrer le serveur web
  Serial.println("All Done!");
  
  // Connexion au point d'accès WIFI
  WiFi.begin(ssid, password);
  Serial.println("\n[*] Connecting to WiFi Network");
  while(WiFi.status() != WL_CONNECTED)
  {
      Serial.print(".");
      delay(100);
  }
  Serial.print("\n[+] Connected to WiFi network with local IP : ");
  Serial.println(WiFi.localIP()); // Affiche l'adresse IP de l'ESP

  // Configuration de la connexion au broker MQTT
  
  client.setServer(mqtt_broker, mqtt_port);
  client.setCallback(callback);
  while (!client.connected()) {
      // Génération d'un identifiant unique pour le client MQTT
      String client_id = "esp32-client-";
      client_id += String(WiFi.macAddress());
      Serial.printf("The client %s connects to the mqtt broker\n", client_id.c_str());
     
      // Tentative de connexion au broker MQTT
      
      if (client.connect(client_id.c_str())) {
          Serial.println("MQTT connected");
          client.setBufferSize(1024);  // change la taille du buffer à 1024 parce que le message JSON est volumineux
          client.subscribe(topic);
      } else {
          Serial.print("failed with state ");
          Serial.print(client.state());
          delay(2000);
      }
  }


  //***************Code pour la barrière*******************//
  pinMode(4,OUTPUT);
  pinMode(15,OUTPUT);
  pinMode(21, INPUT);
  pinMode(22, OUTPUT);
  pinMode(23,OUTPUT);
  pinMode(5, INPUT);
  pinMode(16, INPUT);
  pinMode(17, INPUT);
  pinMode(18, INPUT);

}

// Callback appelé lorsque le client MQTT reçoit un message
void callback(char *topic, byte *payload, unsigned int length) {
  Serial.print("Message arrived in topic: ");
  Serial.println(topic);
  Serial.print("Message:");
   
  // On initialise l'option à une chaîne vide
  liste = "";
  
  // Conversion des données reçues en chaîne de caractères
  for (int i = 0; i < length; i++) {
      liste += (char)payload[i];
  }
  
  Serial.println(liste);
  Serial.println();
  Serial.println("-----------------------");

  // On compte le nombre de fois que le mot "libre" apparaît dans le message reçu
  count = 0;
  int pos = liste.indexOf("libre");
  while (pos >= 0) {
    count++;
    pos = liste.indexOf("libre", pos + 1);
  }
  Serial.print("Le nombre de places libres est ");
  Serial.println(count);
  
  // On appelle la fonction update() pour mettre à jour la page Web avec les nouvelles données du parking
  update();
}

void fermer()
{
  digitalWrite((int)OUVERTURE,LOW);
    digitalWrite((int)FERMETURE,HIGH);
    while(c_close == 1)
    {
      c_open = digitalRead(GATE_OPEN);
      c_close = digitalRead(GATE_CLOSE);
    }
    digitalWrite(OUVERTURE,LOW);
    digitalWrite(FERMETURE,LOW);
}

void ouvrir()
{
  digitalWrite((int)FERMETURE,LOW);
    digitalWrite((int)OUVERTURE,HIGH);
    while(c_open == 1)
    {
      c_open = digitalRead(GATE_OPEN);
      c_close = digitalRead(GATE_CLOSE);
    }
    digitalWrite(FERMETURE,LOW);
    digitalWrite(OUVERTURE,LOW);
}
void loop(){
  dnsServer.processNextRequest(); // On gère les requêtes DNS
  client.loop(); // On maintient la connexion MQTT active

  //***************Code pour la barrière*******************//
  //Lecture des capteurs
  c_open = digitalRead(GATE_OPEN);
  c_close = digitalRead(GATE_CLOSE);
  c_avant = digitalRead(AVANT);
  c_apres = digitalRead(APRES);
  //Serial.printf("Close : %d  Open : %d  apres :%d  avant : %d\n\r",c_close,c_open,c_apres,c_avant);
<<<<<<< HEAD
  if((c_close == 0 && c_open == 1 && c_avant == 0)&&(count != 0)|(c_close == 0 && c_open == 1 && digitalRead(21) == 0) )// Si la barriere est fermée elle ouvre si les conditions sont remplies
=======
  if(((c_close == 0 && c_open == 1 && c_avant == 0)&&(count != 0))|(c_close == 0 && c_open == 1 && digitalRead(21) == 0) )// Si la barriere est fermée
>>>>>>> bfbf01fcaa84f13067916f874213f1b680a27161
  {
    ouvrir();
  }
  if((c_close == 1 && c_open == 0 && c_apres == 0)|(c_close == 1 && c_open == 0 && digitalRead(21) == 0))// Si la barriere est ouverte elle ferme si les conditions sont remplies
  {
    fermer();
  }
  // Gestion de l'état de la lumière selon la position de la barrière
  if (c_open == 0)
  {
    digitalWrite(RED_LIGHT,LOW);
    digitalWrite(GREEN_LIGHT,HIGH);
  }else
  {
    digitalWrite(RED_LIGHT,HIGH);
    digitalWrite(GREEN_LIGHT,LOW);
  }
  
}

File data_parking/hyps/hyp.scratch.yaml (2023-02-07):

# YOLOv5 🚀 by Ultralytics, GPL-3.0 license
# Hyperparameters for COCO training from scratch
# python train.py --batch 40 --cfg yolov5m.yaml --weights '' --data coco.yaml --img 640 --epochs 300
# See tutorials for hyperparameter evolution https://github.com/ultralytics/yolov5#tutorials

lr0: 0.01  # initial learning rate (SGD=1E-2, Adam=1E-3)
lrf: 0.1  # final OneCycleLR learning rate (lr0 * lrf)
momentum: 0.937  # SGD momentum/Adam beta1
weight_decay: 0.0005  # optimizer weight decay 5e-4
warmup_epochs: 3.0  # warmup epochs (fractions ok)
warmup_momentum: 0.8  # warmup initial momentum
warmup_bias_lr: 0.1  # warmup initial bias lr
box: 0.05  # box loss gain
cls: 0.5  # cls loss gain
cls_pw: 1.0  # cls BCELoss positive_weight
obj: 1.0  # obj loss gain (scale with pixels)
obj_pw: 1.0  # obj BCELoss positive_weight
iou_t: 0.20  # IoU training threshold
anchor_t: 4.0  # anchor-multiple threshold
# anchors: 3  # anchors per output layer (0 to ignore)
fl_gamma: 0.0  # focal loss gamma (efficientDet default gamma=1.5)
hsv_h: 0.015  # image HSV-Hue augmentation (fraction)
hsv_s: 0.7  # image HSV-Saturation augmentation (fraction)
hsv_v: 0.4  # image HSV-Value augmentation (fraction)
degrees: 30.0  # image rotation (+/- deg)
translate: 0.1  # image translation (+/- fraction)
scale: 0.5  # image scale (+/- gain)
shear: 0.15  # image shear (+/- deg)
perspective: 0.0005  # image perspective (+/- fraction), range 0-0.001
flipud: 0.5  # image flip up-down (probability)
fliplr: 0.5  # image flip left-right (probability)
mosaic: 1.0  # image mosaic (probability)
mixup: 0.0  # image mixup (probability)
copy_paste: 0.0  # segment copy-paste (probability)

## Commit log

2023-01-19 Ajout des codes Arduino et du schéma électrique KiCad
    [Projet.kicad_pcb, Projet.kicad_sch, captor.kicad_sch]
2023-01-23 Ajout d'un classeur Excel avec les prix du projet pour les TA
    [Prix_robot.xlsx]
2023-01-24 Changement de projet/Suppression des anciens fichiers
    [Prix_robot.xlsx, Projet.kicad_pcb, Projet.kicad_sch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]
2023-02-06 Ajout de la procédure d'installation de YOLOv5
2023-02-06 Ajout de la méthode pour créer un dataset
2023-02-06 Ajout de la méthode d'entraînement de l'IA
2023-02-06 Projet.py : Récupération des données de détection du best.py
2023-02-06 Ajout des étapes de validation de l'entraînement
2023-02-07 Changement de label plein à car
2023-02-07 enlever plein de classes.txt
2023-02-07 Projet.py frame avec rectangle
2023-02-09 Create Installation.md
    Déplacement de la procédure d'installation du README.md à Installation.md
2023-02-13 Ajout du code pour l'écran de stationnement
2023-02-13 Modification des codes camera et ecran qui sont maintenant compatibles entre eux
2023-02-15 Ajout d'un dossier page_web pour la page web
2023-02-16 camera.py - trie des coordonées (pas fonctionnelle)
2023-02-17 Ajout d'un code pour publier en mqtt la liste des places
2023-03-07 Tentatice de mofification de camera.py piur cree une class
2023-03-16 Shemat esp
    [esp.kicad_pcb, esp.kicad_sch]
2023-03-28 Ajout du code de l'ESP pour la page web par point d'accès
2023-03-28 Kicad Final
    [esp-B_Cu.gbr, esp-B_Mask.gbr, esp-B_Silkscreen.gbr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]
2023-04-11 Code de l'ESP commenté
2023-04-11 Code js de la page Web commenté
2023-04-11 Code js de l'ESP commenté
2023-04-24 MAJ Schema
    [esp-B_Cu.gbr, esp-B_Mask.gbr, esp-B_Silkscreen.gbr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]
2023-04-25 Ébauche du code pour la barrière
2023-05-02 Ajout du code de la barriere
2023-05-15 Ajout des fichiers 3D (stl) de la barrière
    [cover_gate.stl, lever_gate.stl, stand_gate.stl]
2023-05-15 Retrait de test_barriere
2023-05-15 En-tête du code de l'ESP
